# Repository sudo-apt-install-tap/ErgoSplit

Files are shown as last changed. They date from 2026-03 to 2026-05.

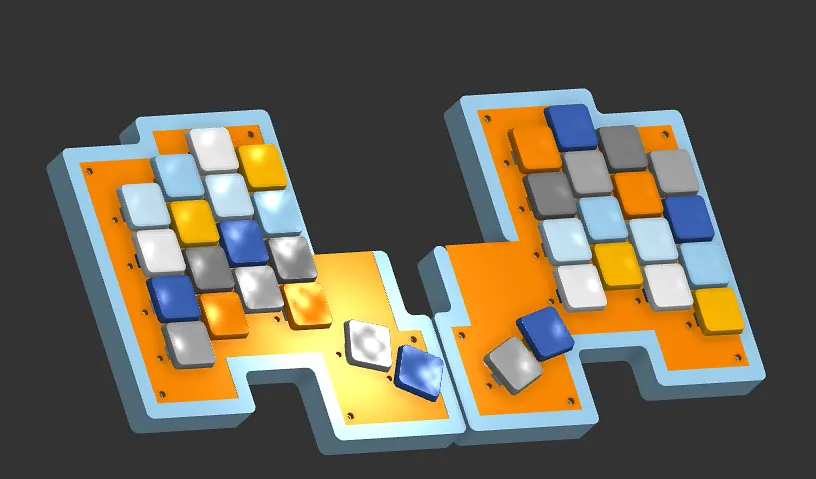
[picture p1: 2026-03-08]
Images/Assembly.png

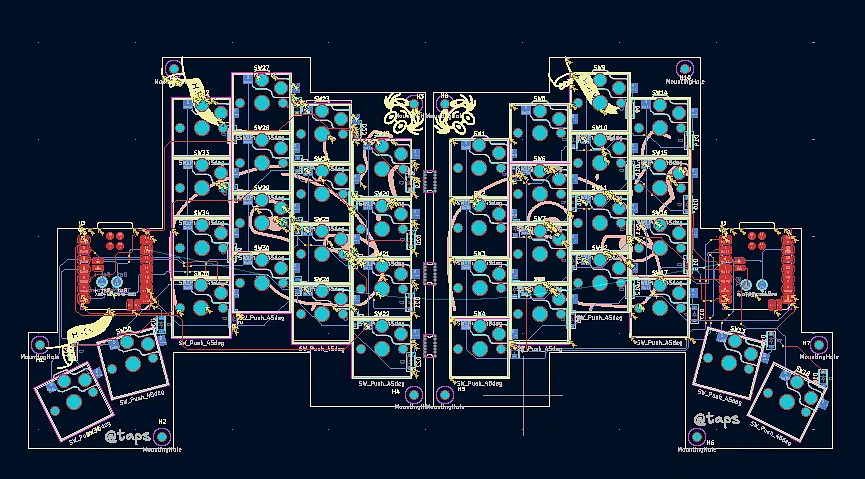
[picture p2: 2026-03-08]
Images/PCB.png

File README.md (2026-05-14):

<div align="center">

Assembly<br>

<h1>
  <b>
    ErgoSplit 
  </b> 
</h1>

<h3> <b> A low-profile split-keyboard! </b> </h1>

</div>

## **Overview**

A split keyboard with a minimalist low profile design!! Symmetrical for easy printing.

### Why?
I wanted a split keyboard thats low profile and looks cool

### How?
Use the firmware in [FIRMWARE](https://github.com/sudo-apt-install-tap/ErgoSplit/tree/main/FIRMWARE) . I've used circuitpy and kmk to do it!

## CAD
CAD files are available at [CAD](https://cad.onshape.com/documents/b054daab3e6eb83ef3a9c97b/w/872555f6aab0d85ae4c614f8/e/704b399ae3f1c5f397311600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)

## Images
<div align="center">
  
Assembly
<br> Full render<br>

---

PCB
<br> PCB

---

Left sch
<br> Left Sch

---

Right sch
<br> Right Sch

### Build Images



Left Build!



Right Build!



Togather!

### VIDEO
[title](https://youtu.be/x2c1Rt32prMl)

## BOM

Name	| Quantity |	Price ( 1 UNIT) |	Price Total |	Runing Total | Link
-------|-------|-------|-------|-------|-------
MCU |	2 |	₹1,160.00 |	₹2,320.00 |	₹2,320.00 |	https://robu.in/product/seeed-studio-xiao-ble-nrf52840/
DIODES |	40 |	₹1.05 |	₹42.00 |	₹2,362.00 |	https://robu.in/product/mm1z27-slkor-sod-123-zener-diodes-rohs/
Hotswap Socket (Pack of 10) |	4 |	145 | 	₹580.00 |	₹2,942.00 |	https://neomacro.in/products/kailh-choc-pg1350-hot-swap-sockets?variant=48049369907478
Kailh Choc V1 (Pack of 10) |	4 |	₹480.00 |	₹1,920.00 |	₹4,862.00 |	https://neomacro.in/products/kailh-choc-v1-switches?variant=48049336025366
Keycaps 1U (Pack of 10) |	4 |	₹350.00 |	₹1,400.00 |	₹6,262.00 |	https://neomacro.in/products/chocfox-cfx-choc-blank-keycaps?variant=50664114913558
Homing Keys (Pack of 2) |	1 |	₹70.00 |	₹70.00 |	₹6,332.00 |	https://neomacro.in/products/chocfox-cfx-choc-blank-keycaps?variant=48049351590166
PCB |	5 |	₹470.00 |	₹2,350.00 |	₹8,682.00 |	https://jlcpcb.com/
Total |	--- |	---	| --- |	₹8,682.00	| ---
Round off total				~ 8.75k INR

### Total: $95
### Print Legion Shipping: $5
### Grand Total: $100

</div>

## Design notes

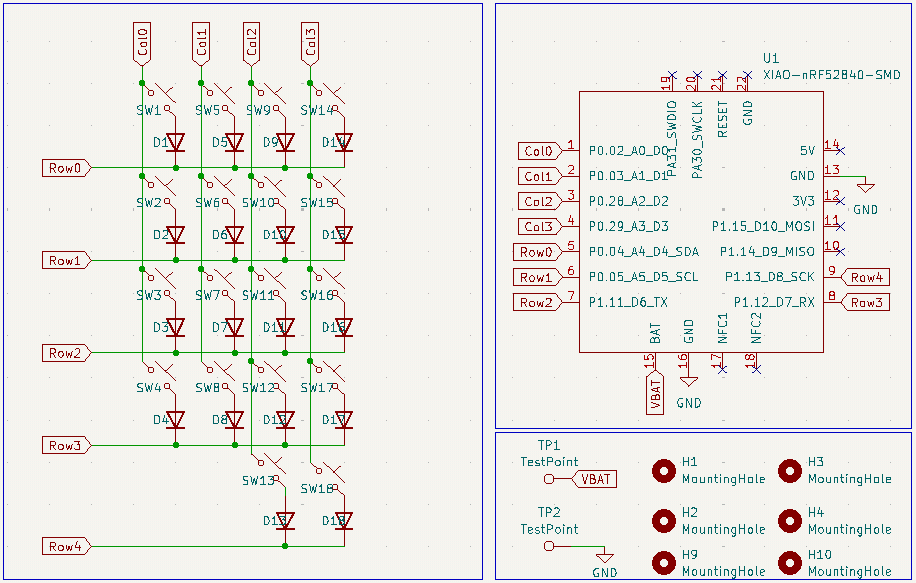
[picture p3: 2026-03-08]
Images/Left sch.png

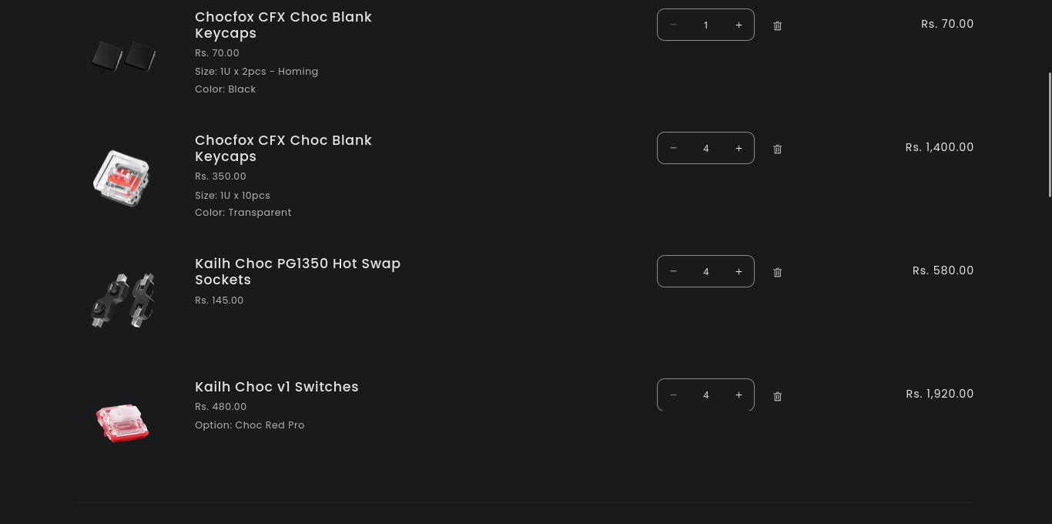
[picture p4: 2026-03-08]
Images/CART/NEOMACRO.png

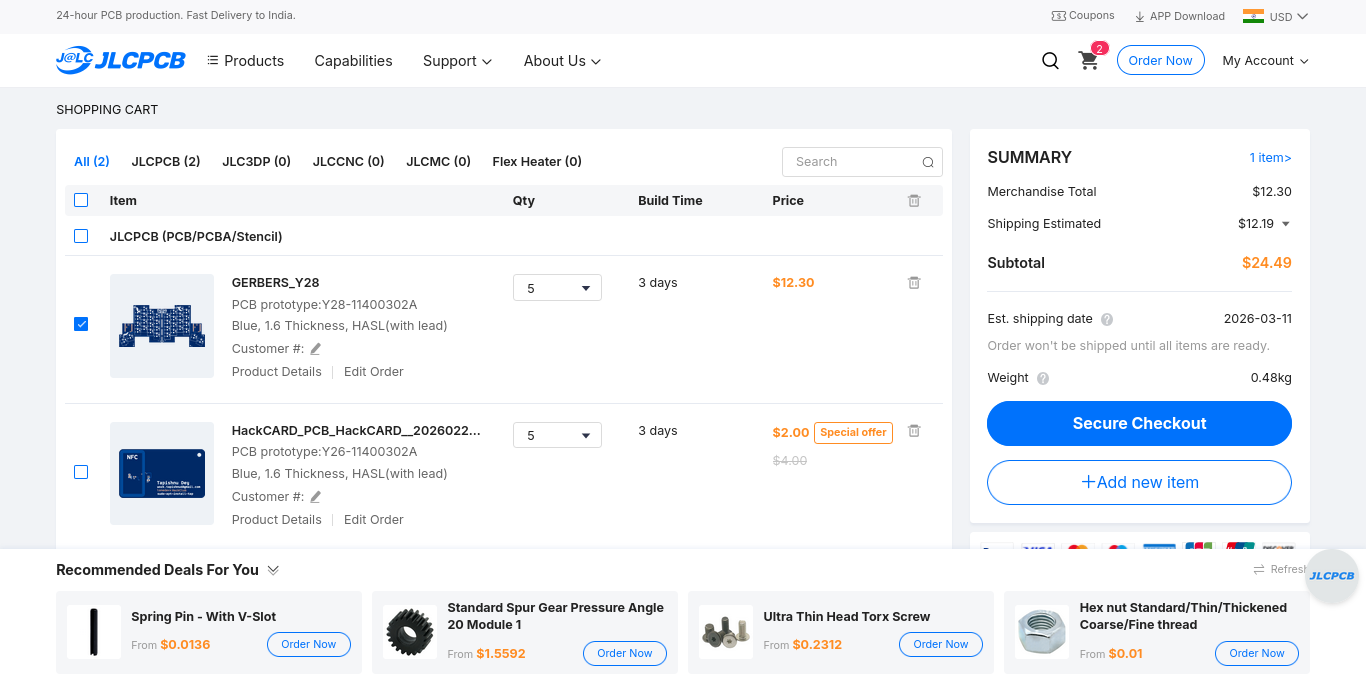
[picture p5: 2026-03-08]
Images/CART/JLCPCB.png

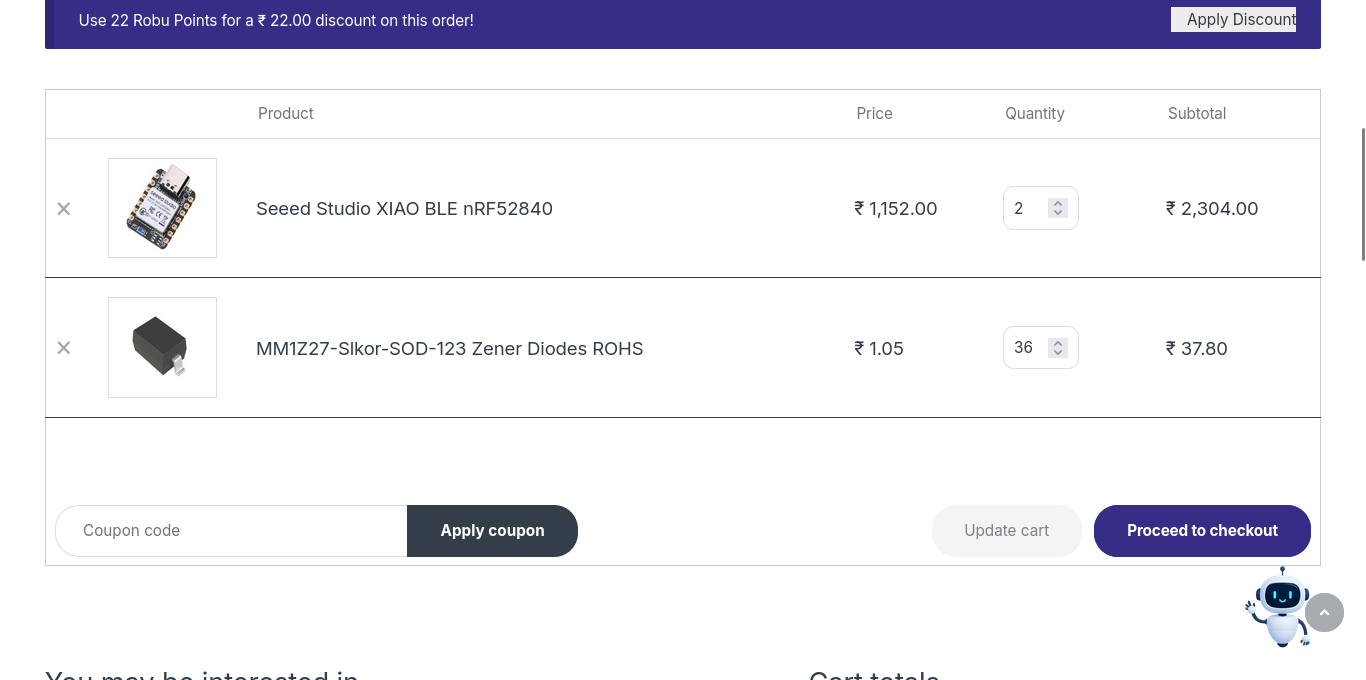
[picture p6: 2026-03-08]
Images/CART/ROBU.png

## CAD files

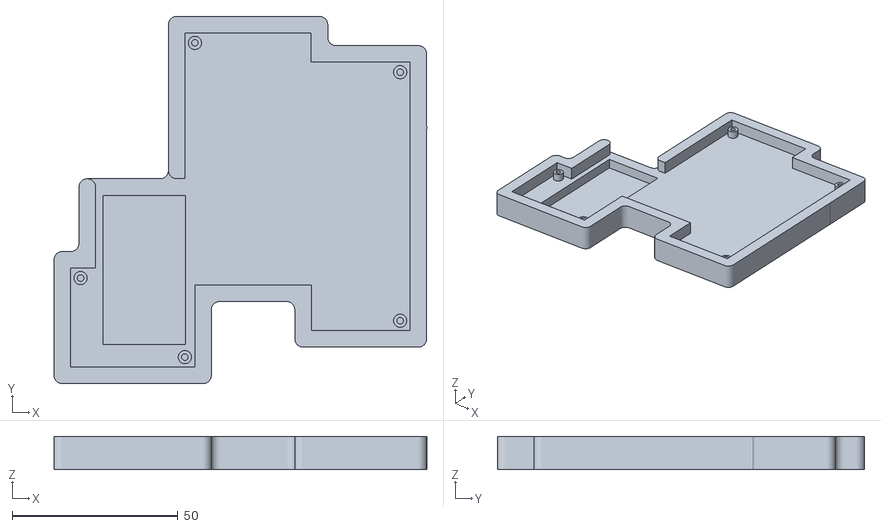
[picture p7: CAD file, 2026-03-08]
CAD/Left Case.stl
112.6 x 110.9 x 10.0

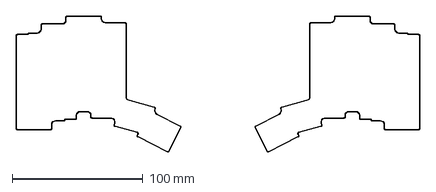
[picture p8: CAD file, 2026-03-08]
ergogen/outlines/bottom.dxf
308.5 x 103.8 mm

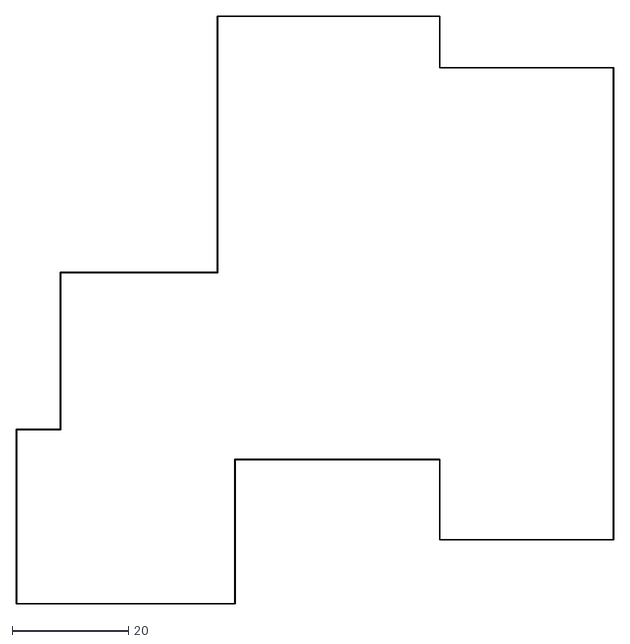
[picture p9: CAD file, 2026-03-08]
KiCAD/Halfs/Left-Edge_Cuts.dxf
102.6 x 101.0

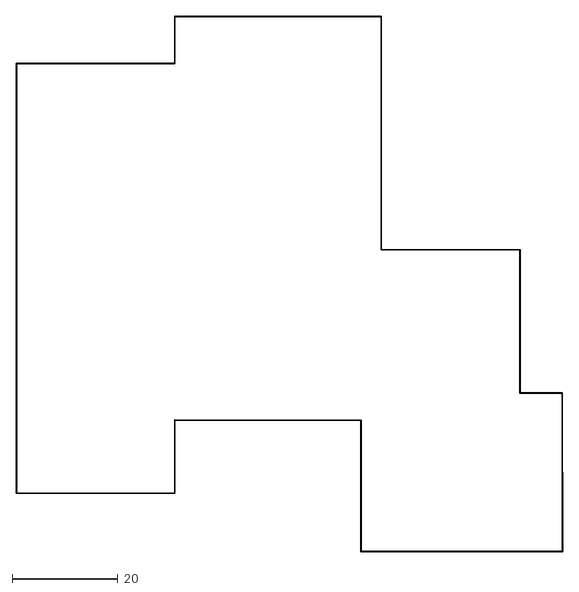
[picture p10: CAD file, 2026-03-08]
KiCAD/Halfs/Right-Edge_Cuts.dxf
103.1 x 101.0

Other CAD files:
CAD/Right Case.stl

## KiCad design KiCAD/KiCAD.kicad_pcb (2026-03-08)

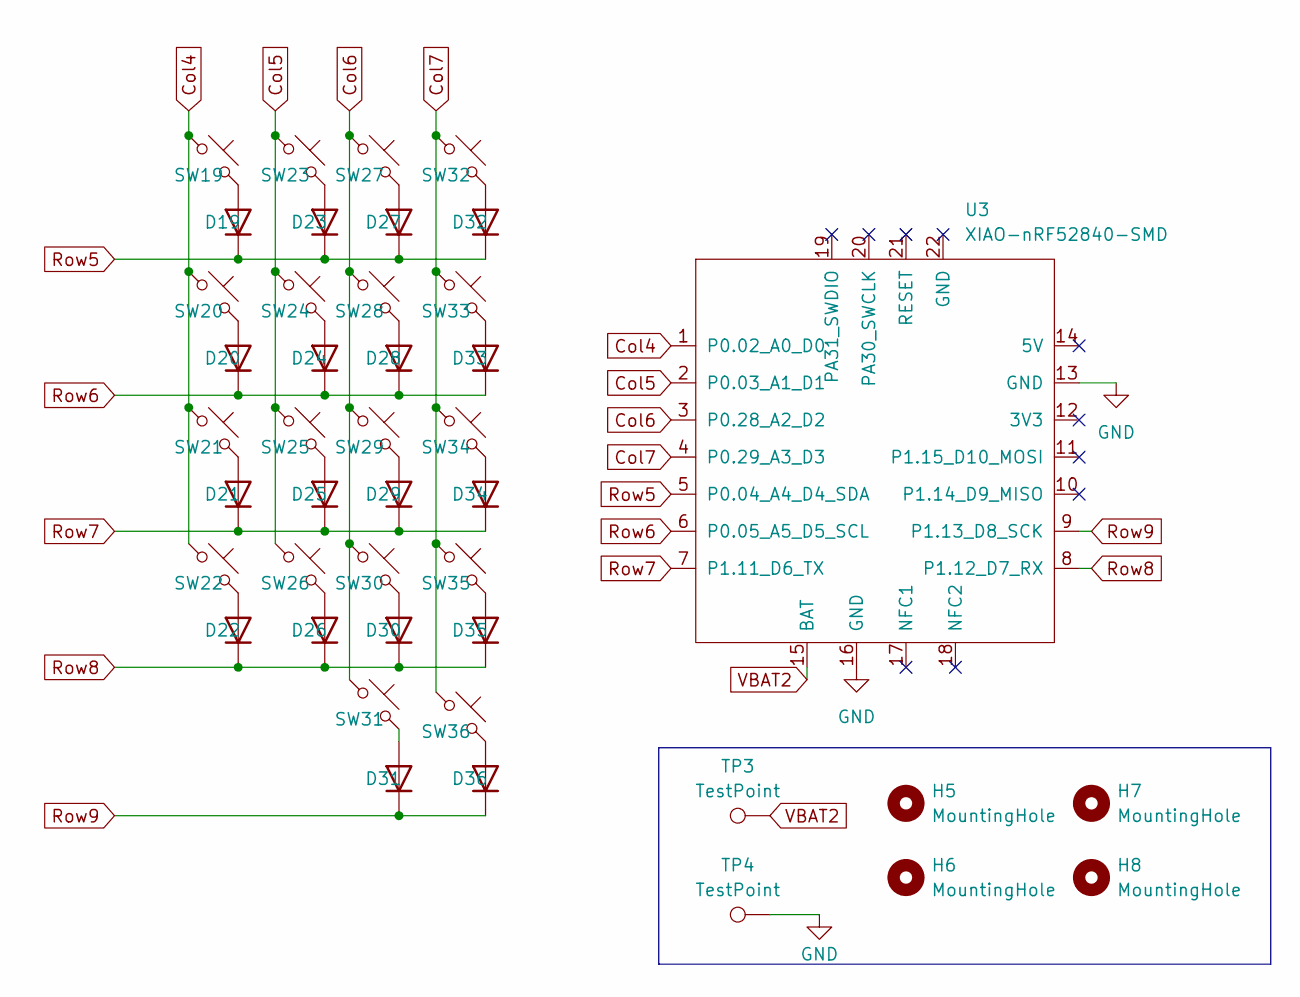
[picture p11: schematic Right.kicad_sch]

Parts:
D19, D20, D21, D22, D23, D24, D25, D26, D27, D28, D29, D30, D31, D32, D33, D34, D35, D36: D; D_SOD-123
H5, H6, H7, H8: MountingHole; MountingHole_2.2mm_M2
SW19, SW20, SW21, SW22, SW23, SW24, SW25, SW26, SW27, SW28, SW29, SW30, SW31, SW32, SW33, SW34, SW35, SW36: SW_Push_45deg; SW_Hotswap_Kailh_Choc_V1
TP3, TP4: TestPoint; TestPoint_Pad_D2.0mm
U3: XIAO-nRF52840-SMD

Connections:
Col4: SW19.1, SW20.1, SW21.1, SW22.1, U3.1 (P0.02_A0_D0)
Col5: SW23.1, SW24.1, SW25.1, SW26.1, U3.2 (P0.03_A1_D1)
Col6: SW27.1, SW28.1, SW29.1, SW30.1, SW31.1, U3.3 (P0.28_A2_D2)
Col7: SW32.1, SW33.1, SW34.1, SW35.1, SW36.1, U3.4 (P0.29_A3_D3)
GND: TP4.1, U3.13 (GND), U3.16 (GND); also elsewhere on the board
unnamed: D19.2 (A), SW19.2
unnamed: D20.2 (A), SW20.2
unnamed: D21.2 (A), SW21.2
unnamed: D22.2 (A), SW22.2
unnamed: D23.2 (A), SW23.2
unnamed: D24.2 (A), SW24.2
unnamed: D25.2 (A), SW25.2
unnamed: D26.2 (A), SW26.2
unnamed: D27.2 (A), SW27.2
unnamed: D28.2 (A), SW28.2
unnamed: D29.2 (A), SW29.2
unnamed: D30.2 (A), SW30.2
unnamed: D31.2 (A), SW31.2
unnamed: D32.2 (A), SW32.2
unnamed: D33.2 (A), SW33.2
unnamed: D34.2 (A), SW34.2
unnamed: D35.2 (A), SW35.2
unnamed: D36.2 (A), SW36.2
Row5: D19.1 (K), D23.1 (K), D27.1 (K), D32.1 (K), U3.5 (P0.04_A4_D4_SDA)
Row6: D20.1 (K), D24.1 (K), D28.1 (K), D33.1 (K), U3.6 (P0.05_A5_D5_SCL)
Row7: D21.1 (K), D25.1 (K), D29.1 (K), D34.1 (K), U3.7 (P1.11_D6_TX)
Row8: D22.1 (K), D26.1 (K), D30.1 (K), D35.1 (K), U3.8 (P1.12_D7_RX)
Row9: D31.1 (K), D36.1 (K), U3.9 (P1.13_D8_SCK)
VBAT2: TP3.1, U3.15 (BAT); also elsewhere on the board

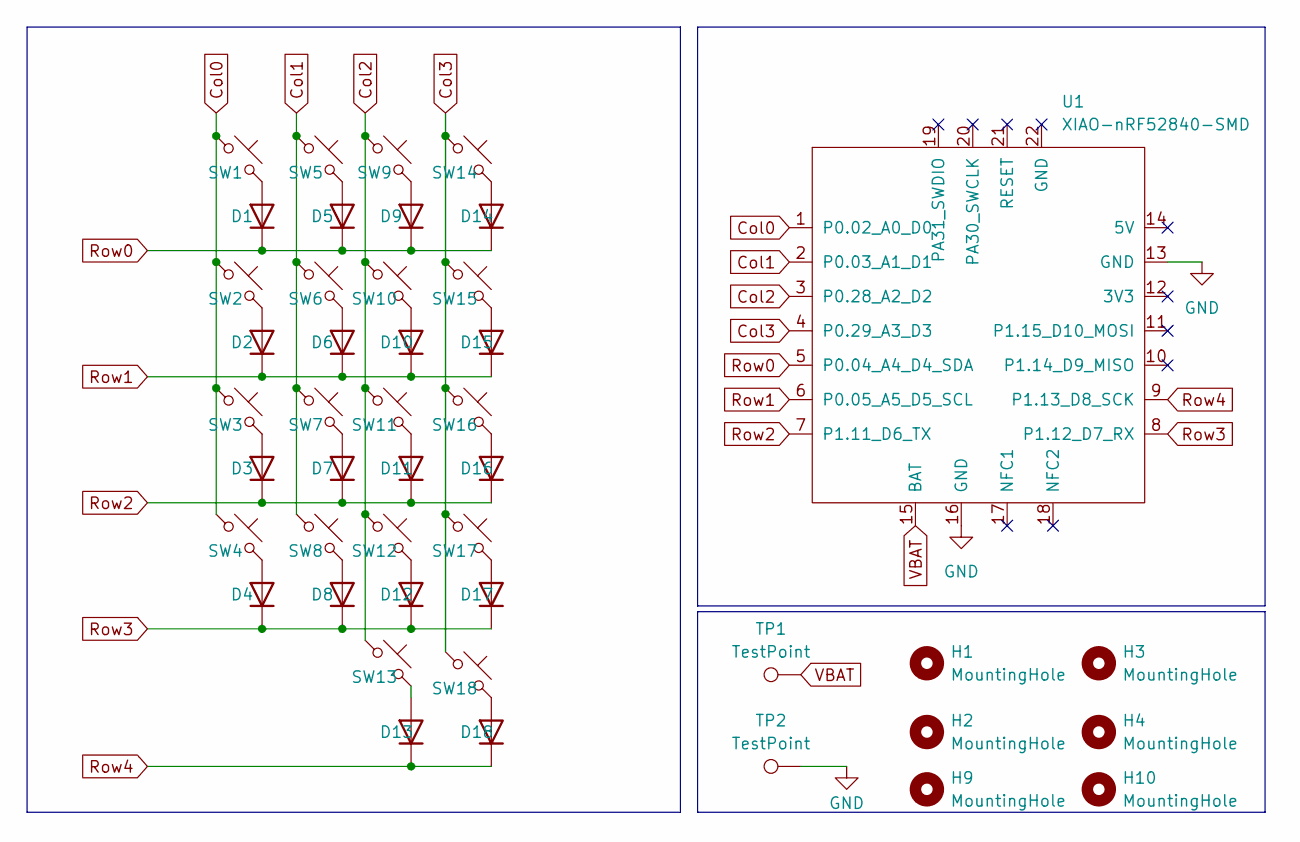
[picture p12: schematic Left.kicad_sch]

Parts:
D1, D2, D3, D4, D5, D6, D7, D8, D9, D10, D11, D12, D13, D14, D15, D16, D17, D18: D; D_SOD-123
H1, H2, H3, H4, H9, H10: MountingHole; MountingHole_2.2mm_M2
SW1, SW2, SW3, SW4, SW5, SW6, SW7, SW8, SW9, SW10, SW11, SW12, SW13, SW14, SW15, SW16, SW17, SW18: SW_Push_45deg; SW_Hotswap_Kailh_Choc_V1
TP1, TP2: TestPoint; TestPoint_Pad_D2.0mm
U1: XIAO-nRF52840-SMD

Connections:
Col0: SW1.1, SW2.1, SW3.1, SW4.1, U1.1 (P0.02_A0_D0)
Col1: SW5.1, SW6.1, SW7.1, SW8.1, U1.2 (P0.03_A1_D1)
Col2: SW9.1, SW10.1, SW11.1, SW12.1, SW13.1, U1.3 (P0.28_A2_D2)
Col3: SW14.1, SW15.1, SW16.1, SW17.1, SW18.1, U1.4 (P0.29_A3_D3)
GND: TP2.1, U1.13 (GND), U1.16 (GND); also elsewhere on the board
unnamed: D1.2 (A), SW1.2
unnamed: D2.2 (A), SW2.2
unnamed: D3.2 (A), SW3.2
unnamed: D4.2 (A), SW4.2
unnamed: D5.2 (A), SW5.2
unnamed: D6.2 (A), SW6.2
unnamed: D7.2 (A), SW7.2
unnamed: D8.2 (A), SW8.2
unnamed: D9.2 (A), SW9.2
unnamed: D10.2 (A), SW10.2
unnamed: D11.2 (A), SW11.2
unnamed: D12.2 (A), SW12.2
unnamed: D13.2 (A), SW13.2
unnamed: D14.2 (A), SW14.2
unnamed: D15.2 (A), SW15.2
unnamed: D16.2 (A), SW16.2
unnamed: D17.2 (A), SW17.2
unnamed: D18.2 (A), SW18.2
Row0: D1.1 (K), D5.1 (K), D9.1 (K), D14.1 (K), U1.5 (P0.04_A4_D4_SDA)
Row1: D2.1 (K), D6.1 (K), D10.1 (K), D15.1 (K), U1.6 (P0.05_A5_D5_SCL)
Row2: D3.1 (K), D7.1 (K), D11.1 (K), D16.1 (K), U1.7 (P1.11_D6_TX)
Row3: D4.1 (K), D8.1 (K), D12.1 (K), D17.1 (K), U1.8 (P1.12_D7_RX)
Row4: D13.1 (K), D18.1 (K), U1.9 (P1.13_D8_SCK)
VBAT: TP1.1, U1.15 (BAT); also elsewhere on the board

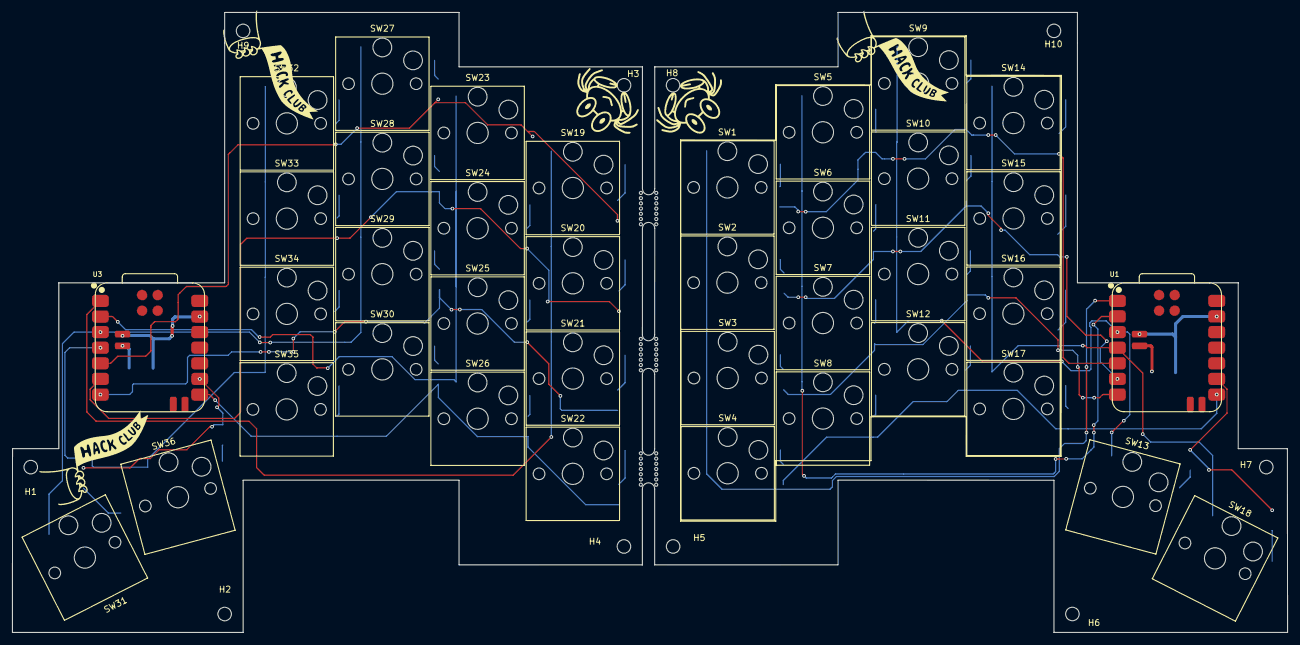
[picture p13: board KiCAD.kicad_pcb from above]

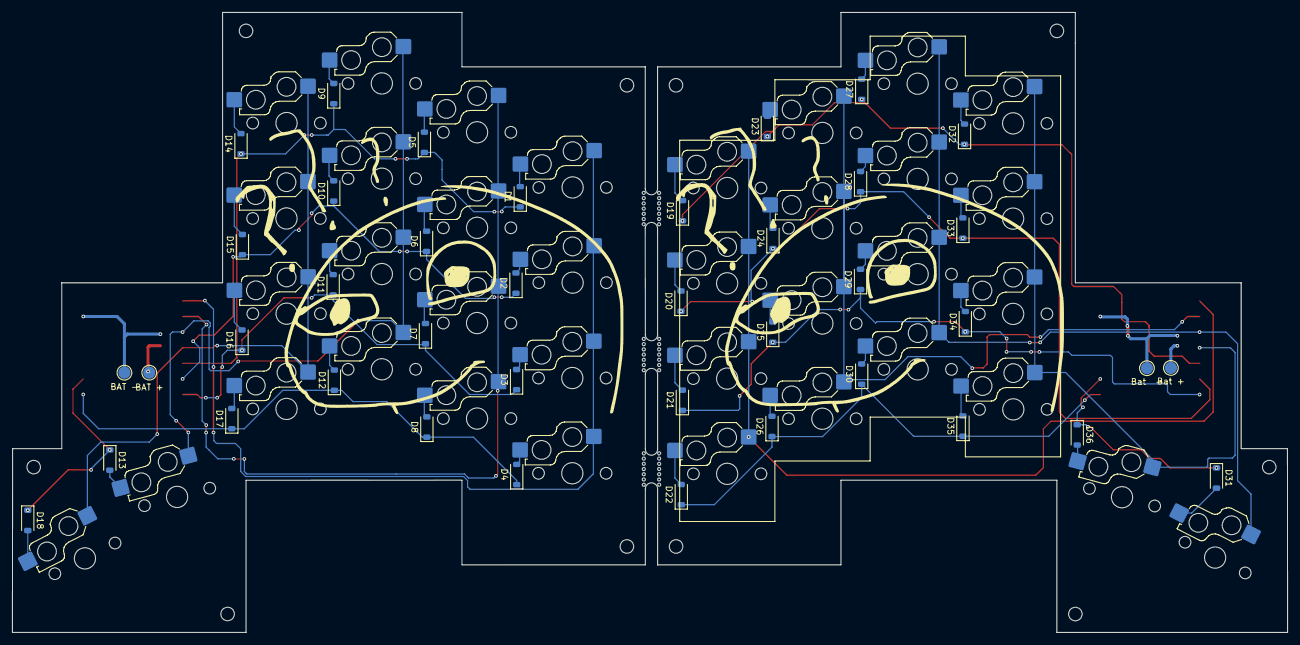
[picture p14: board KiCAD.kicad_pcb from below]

Board: 2 copper layers, 207.5 x 100.9 mm, 88 parts (40 on the bottom side), 57 nets.

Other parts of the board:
BAT +: TestPoint; TestPoint_Pad_D2.0mm
BAT -: TestPoint; TestPoint_Pad_D2.0mm
Bat  -: TestPoint; TestPoint_Pad_D2.0mm
Bat +: TestPoint; TestPoint_Pad_D2.0mm

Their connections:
GND: BAT -.1, Bat -.1; also elsewhere on the board
VBAT: BAT +.1; also elsewhere on the board
VBAT2: Bat +.1; also elsewhere on the board

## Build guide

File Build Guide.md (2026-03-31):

# BUILD GUIDE FOR TAO TE CHING <br>

## Intro:
<h4>Okay, now you have your PCB and components in hand and are ready to build it! I've tried to make this guide as comprehensive as possible, but you are free to improve it and submit a PR to this repo. </h4>
<br>

## Tools Required
- Soldering iron
- Solder
- Tweezers
- Flux (recommended)
- USB cable
- Multimeter (optional but helpful)

<br>

## Recommended Build Order
1. Solder diodes
2. Solder hotswap sockets
3. Solder MCU
4. Install switches
5. Flash firmware
6. Test the matrix

<br>

## Diodes
<h4>
N.T: Match the stripe on the diode with the line on the PCB silkscreen. The stripe indicates the cathode. If the diode is reversed the keyboard matrix will not work. <br><br>

Firstly tin one of the pads of the diodes, then using tweezers hold the diodes down and then melt the solder and hold it. In the end it should look something like this: </h4>
<br>
<div align="center">

</div>

## HotSwap Sockets
<h4> N.T: I have used TTC Pokayoke Hotswap Sockets V2 which are compatible with Kailh socket footprints and are reversable. If you have used Kailh or any other sockets which are NOT reversible please pay attention to the orientation as it can cause problems later down the line while snapping in the plate. <br><br>

I recommend not tinning the pads before putting the sockets in. So you just want to place the sockets in the hole and align it with the footprint. Now you want to add solder to the pads. Keep the solder molten and switch to your tweezers to now put pressure on the socket so it sits flush. Now after it has solidified, solder the other pad too. Now! It should look like this: </h4>
<div align="center">

</div>
<br>

## MCU
<h4> For the Tao Te Ching keyboard I used the <b>XIAO RP2350</b>. Make sure the MCU is oriented correctly before soldering it to the PCB. Incorrect orientation may prevent the keyboard from functioning or could damage the board. <br><br>

First place the MCU onto the footprint and ensure that all pins line up properly with the pads on the PCB. Once aligned, you may want to temporarily secure the board with a small piece of tape or hold it in place while soldering. <br><br>

Begin by soldering <b>one corner pin</b>. After this, check that the MCU sits flat against the PCB and that all pins are aligned correctly. If necessary, reheat the solder joint and adjust the position of the MCU. <br><br>

Once you are satisfied with the alignment, proceed to solder the remaining pins. Take your time and make sure each pin is properly connected to its pad. <br><br>

After soldering, visually inspect the pins to ensure there are <b>no solder bridges</b> between them.
</h4>
<div align="center">

</div>
<br>

## Switches:
<h4>
  For the switches you can just press the switches into the plate and then align the plate with the PCB and HotSwap sockets and just push them in column by column. Theres not much to do here!
</h4> <br>

## Firmware: 
While pressing down the boot button on your MCU plug it in, wait till a drive pops up. Get the circuitpython uf2 from [HERE](https://circuitpython.org/board/seeeduino_xiao_rp2350/). <br> <br>
Add /kmk from the kmk library from [HERE](https://github.com/KMKfw/kmk_firmware) to the drive that appears. <br> <br> Now get the code from [/firmware](firmware) and add it to the respective MCUs.

## AND YOU ARE DONE!!!

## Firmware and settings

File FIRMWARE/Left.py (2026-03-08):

import board
from kmk.kmk_keyboard import KMKKeyboard
from kmk.scanners import DiodeOrientation
from kmk.keys import KC
from kmk.modules.split import Split, SplitType

keyboard = KMKKeyboard()

keyboard.col_pins = (board.D0, board.D1, board.D2, board.D3)
keyboard.row_pins = (board.D4, board.D5, board.D6, board.D7, board.D8)
keyboard.diode_orientation = DiodeOrientation.COL2ROW

split = Split(
    split_type=SplitType.BLE,
    use_weighted=False,
    is_left=True,
)
keyboard.modules.append(split)

keyboard.keymap = [
    [
        KC.ESC,  KC.Q,    KC.W,    KC.E,    KC.R,    KC.T,    KC.Y,    KC.U,
        KC.TAB,  KC.A,    KC.S,    KC.D,    KC.F,    KC.G,    KC.H,    KC.J,
        KC.LSFT, KC.Z,    KC.X,    KC.C,    KC.V,    KC.B,    KC.N,    KC.M,
        KC.LCTL, KC.LALT, KC.SPC,  KC.ENT,  KC.BSPC, KC.DEL,  KC.RSFT, KC.RCTL,
        KC.NO,   KC.NO,   KC.SPC,  KC.ENT,  KC.NO,   KC.NO,   KC.NO,   KC.NO,
    ]
]

if __name__ == '__main__':
    keyboard.go()

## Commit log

2026-03-08 Added BOM
    [BOM.csv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]
2026-03-08 Update README with BOM and additional details
    Added detailed BOM with component links and pricing.
2026-03-08 Revise README with detailed project information
    Updated the README to include additional details about the ErgoSplit keyboard, including an overview, reasons for design choices, CAD file links, images, and a bill of materials (BOM).
2026-03-08 Update README with additional images and BOM details
2026-03-08 Added case stls
    [Left Case.stl, Right Case.stl]
